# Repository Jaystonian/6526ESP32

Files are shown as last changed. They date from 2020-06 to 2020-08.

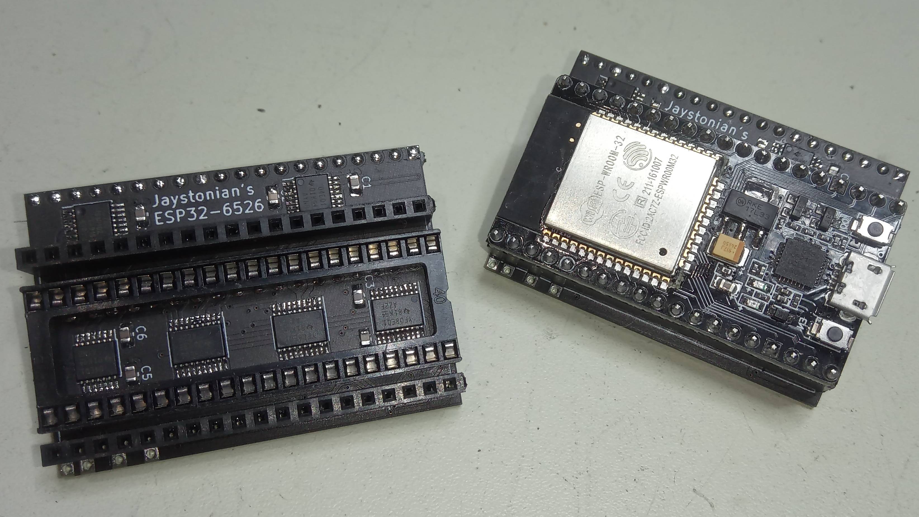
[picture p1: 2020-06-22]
pics/IMG_20200618_071035_0.jpg

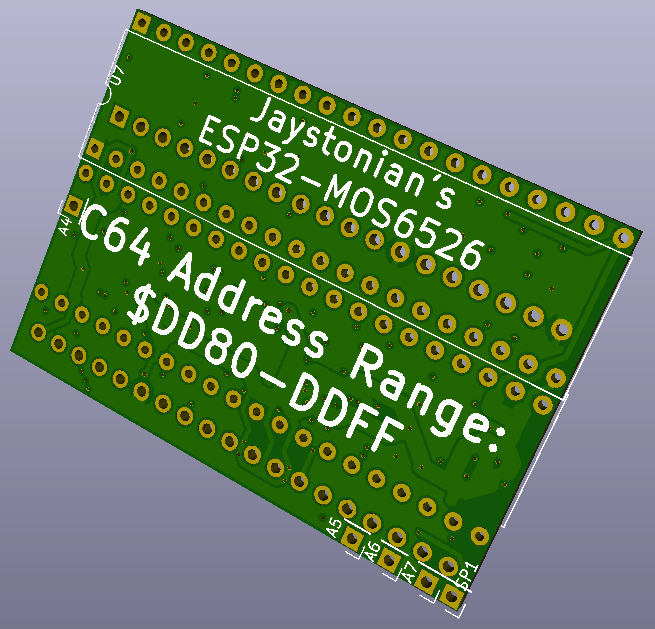
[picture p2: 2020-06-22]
pics/6526ESP32-Bottom.png

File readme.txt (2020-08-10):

6526ESP32

v0.1 - Largely disabled wifi, device boots into Ready mode instead of Modem mode
     - Added 1541diag cartridge (to use, poke 56704,5:poke 56705,0:sys56777)
     - Added Tool-64 cartridge (to use, poke 56704,5:poke 56705,1:sys56777)
     - Intended to use a new version of BASIC with new commands to use the
     device easily without pokes or sys calls, and also replace math etc.

v0.0 - straight conversion from ESP8266, added a few things but very dirty

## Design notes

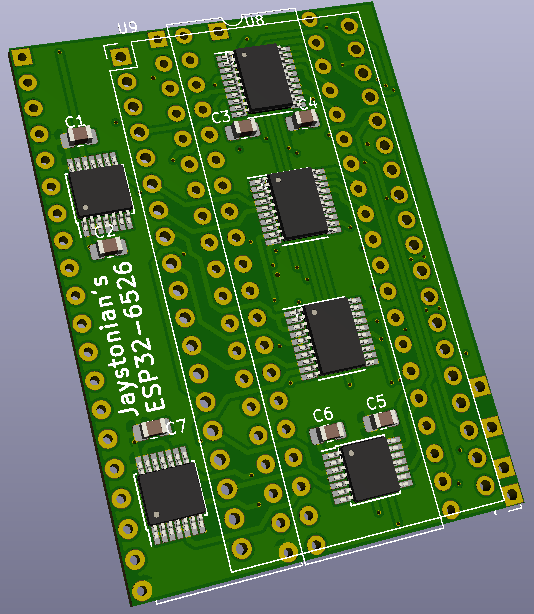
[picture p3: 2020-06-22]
pics/6526ESP32-Top.png

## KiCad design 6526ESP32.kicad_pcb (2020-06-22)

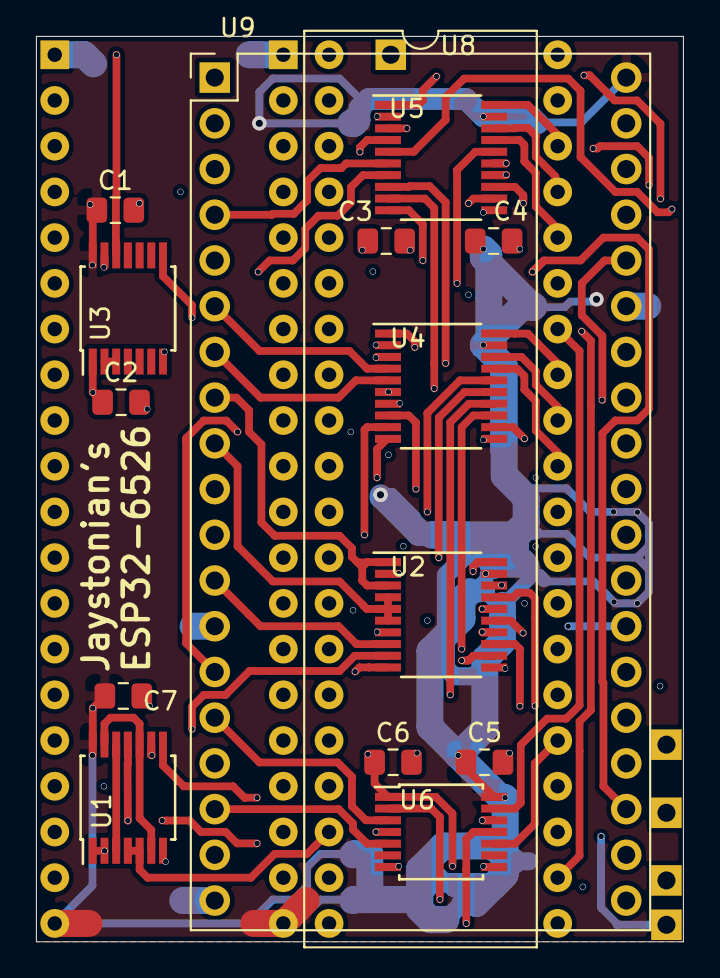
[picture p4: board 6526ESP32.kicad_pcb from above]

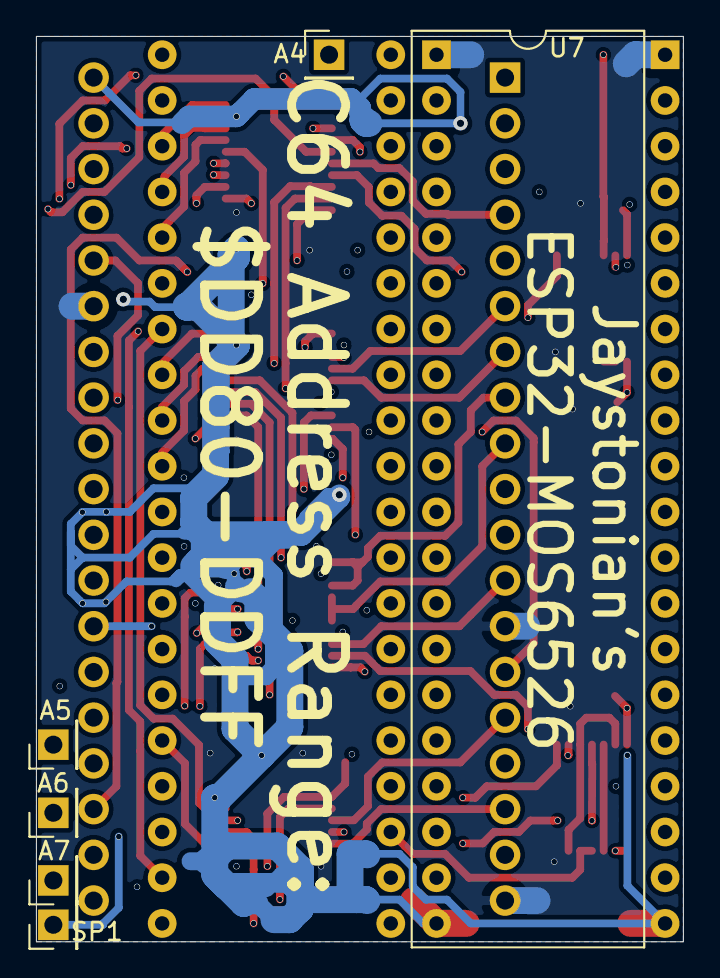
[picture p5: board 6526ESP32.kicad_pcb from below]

Board: 4 copper layers, 35.9 x 50.3 mm, 21 parts (5 on the bottom side), 78 nets.

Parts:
A4: A4; PinHeader_1x01_P2.54mm_Vertical
A5: A5; PinHeader_1x01_P2.54mm_Vertical
A6: A6; PinHeader_1x01_P2.54mm_Vertical
A7: A7; PinHeader_1x01_P2.54mm_Vertical
C1, C2, C3, C4, C5, C6, C7: 100n; C_0805_2012Metric_Pad1.15x1.40mm_HandSolder
SP1: SP1; PinHeader_1x01_P2.54mm_Vertical
U1: 74ABT00PW,112; TSSOP-14_4.4x5mm_P0.65mm
U2, U4, U5: TXS0108EQPWRQ1; TSSOP-20_4.4x6.5mm_P0.65mm
U3, U6: TXS0104EPW; TSSOP-14_4.4x5mm_P0.65mm
U7: MOS6526_SOCKET; DIP-40_W15.24mm
U8: MOS6526_CHIP; DIP-40_W15.24mm
U9: ESP32-DEVKIT-C; ESP32-DEV1

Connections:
+3V3: C2.1, C3.1, C6.1, U2.2, U3.1, U4.2, U5.2, U6.1, U6.8, U9.20
+5V: C1.1, C4.1, C5.1, C7.1, U1.14, U2.19, U3.14, U4.19, U5.19, U6.14, U7.20, U8.20, U9.38
/A0: U5.20, U7.38, U8.38
/A0_3V: U5.1, U9.24
/A1: U5.18, U7.37, U8.37
/A1_3V: U5.3, U9.25
/A2: U5.17, U7.36, U8.36
/A2_3V: U5.4, U9.22
/A3: U5.16, U7.35, U8.35
/A3_3V: U5.5, U9.23
/A4: A4.1, U5.15
/A4_3V: U5.6, U9.4
/A5: A5.1, U5.14
/A5_3V: U5.7, U9.10
/A6: A6.1, U5.13
/A6_3V: U5.8, U9.31
/A7: A7.1, U1.1, U1.2, U1.9
/CHIP~RESET: U6.13, U7.34, U8.34
/CHIP~RESET~3V: U6.2, U9.21
/CLK: U6.10, U7.25, U8.25
/CLK_3V: U6.5, U9.17
/CNT2: U3.12, U7.40, U8.40
/D0: U4.20, U7.33, U8.33
/D0_3V: U4.1, U9.27
/D1: U4.18, U7.32, U8.32
/D1_3V: U4.3, U9.14
/D2: U4.17, U7.31, U8.31
/D2_3V: U4.4, U9.6
/D3: U4.16, U7.30, U8.30
/D3_3V: U4.5, U9.7
/D4: U4.15, U7.29, U8.29
/D4_3V: U4.6, U9.30
/D5: U4.12, U7.28, U8.28
/D5_3V: U4.9, U9.28
/D6: U4.13, U7.27, U8.27
/D6_3V: U4.8, U9.29
/D7: U4.14, U7.26, U8.26
/D7_3V: U4.7, U9.34
/ENABLEMODEM_3V: U2.10, U3.8, U9.5
/GATE_ENABLE_3V: U4.10, U5.10, U9.32
/MODEM_CTS_3V: U2.8, U9.12
/MODEM_DCD_3V: U2.9, U9.18
/MODEM_RTS_3V: U2.7, U9.11
/MODEM_RXD_3V: U2.1, U2.3, U9.8
/MODEM_TXD_3V: U2.4, U2.5, U2.6, U9.9
/PA0: U7.2, U8.2
/PA1: U7.3, U8.3
/PA2: U2.20, U7.4, U8.4
/PA3: U7.5, U8.5
/PA4: U7.6, U8.6
/PA5: U7.7, U8.7
/PA6: U7.8, U8.8
/PA7: U7.9, U8.9
/PB0: U2.16, U7.10, U8.10
/PB1: U2.14, U7.11, U8.11
/PB2: U7.12, U8.12
/PB3: U7.13, U8.13
/PB4: U2.12, U7.14, U8.14
/PB5: U7.15, U8.15
/PB6: U2.13, U7.16, U8.16
/PB7: U3.13, U7.17, U8.17
/R~W: U5.12, U7.22, U8.22
/R~W~_3V: U5.9, U9.26
/SP1: SP1.1, U2.18
/SP2: U2.15, U7.39, U8.39
/TOD: U7.19, U8.19
/~CE: U1.4, U1.5, U7.23
/~CE6526: U1.11, U8.23
/~CHIPSELECT: U1.8, U6.12
/~CHIPSELECT3V: U6.3, U9.15
/~FLAG2: U2.17, U7.24, U8.24
/~NMI: U6.11, U7.21, U8.21
/~NMI_3V: U6.4, U9.16
/~PC: U7.18, U8.18
GND: C1.2, C2.2, C3.2, C4.2, C5.2, C6.2, C7.2, U1.7, U2.11, U3.7, U4.11, U5.11, U6.7, U7.1, U8.1, U9.13, U9.19, U9.33
unnamed: U1.6, U1.10, U1.13
unnamed: U1.3, U1.12
unnamed: U3.2, U3.3

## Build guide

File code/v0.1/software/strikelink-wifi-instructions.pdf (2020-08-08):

## Strikelink WiFi Instructions

I hope you enjoy your new Strikelink WiFi! The esp8266 module on the board has already been flashed with the latest firmware and pre-configured for 9600 baud use.

To get the proper use out of your unit, do the following to set up:

1. With your C64 powered OFF, Plug the Strikelink WiFi into the C64 User Port, Strikelink WiFi Logo side UP.
2. Turn on computer, and load CCGMS 2017 v4
3. Press F7 to enter the program settings menu, select UP9600 / EZ232 under modem type, and change the baud rate to 9600 baud
4. Save Phonebook and Config
5. Press Return to enter Terminal Mode
6. Press Return. Your Strikelink should say hello to you!
7. Press F8 to enter Anscii Mode (Anscii is a combination of Ascii and Ansi. CCGMS will interpret Ansi colors in Ascii mode). Anscii mode helps the modem properly interpret your WiFi router SSID and Password.
8. Type at$ssid=yourssidgoeshere (Then press Return)
9. Type at$pass=yourpasswordgoeshere (Then press Return)
10.Type atc1 to Connect (atc1 connects to your WiFi, atc0 disconnects)
11.Type at&w to write your settings to the Strikelink WiFi. These will be permanently saved, so in the future, you can load CCGMS 2017 v4, press return, and you should automatically be ready to call BBSes. If your Strikelink ever fails to connect to your router / WiFi access point, just type atc1 to try connecting again.
12.Press F8 to return to Graphics mode, and use the Autodialer in CCGMS 2017 v4 to start calling C64 BBS Systems. You can save your User ID and Password for BBSes in CCGMS 2017 v4 and send them to the BBS you call by pressing F6 and F8, respectively. It makes logging in much easier!

Notes:

– You should be able to stay in 9600 baud mode for most boards you call, even boards that run at lower baud rates. If you ever need to change your baud rate on the Strikelink, just type at$sb=newbaudrate in terminal mode (ex. at$sb=2400), then switch to the F7 menu in CCGMS 2017 v4 and select the corresponding baud rate (ex.2400). Return to terminal mode, and you will now be operating at your new baud rate.
– If you switch to use the User Port 300-2400 modem type in CCGMS 2017 v4 (instead of the UP9600 / EZ232 modem), you'll need to turn off hardware flow control. at&k0 will turn off hardware flow control. at&k1 will turn it back on. You must have hardware flow control on when using the UP9600 / EZ232 modem or bad things will happen :). As the UP9600 / EZ232 modem setting should be fine for calling all BBS Systems, you should really never need to do this.
– The terminal command 'at?' should give you a list of available modem at commands. If this flies by too fast, switch to 2400 baud to see the full menu.
– If your WiFi ever stops working, use the reset button on the WiFi unit or power off your C64 and restart your computer.
– DO NOT USE external 5v usb power at the same time you have your Strikelink WiFi plugged in. This could damage your Strikelink or C64. If you wish to use external usb power instead of the C64 power, cut the trace going to pin 2 on the c64 user port. (top of the board, right side). The Strikelink could draw too much current on C64s not utilizing a newer heavy duty power supply, causing issues. In that case, cutting the trace and using external power is recommended.

How to use external USB power instead of C64 Power.

## This is the top side of the board, with the Strikelink WiFi logo on the

left side.

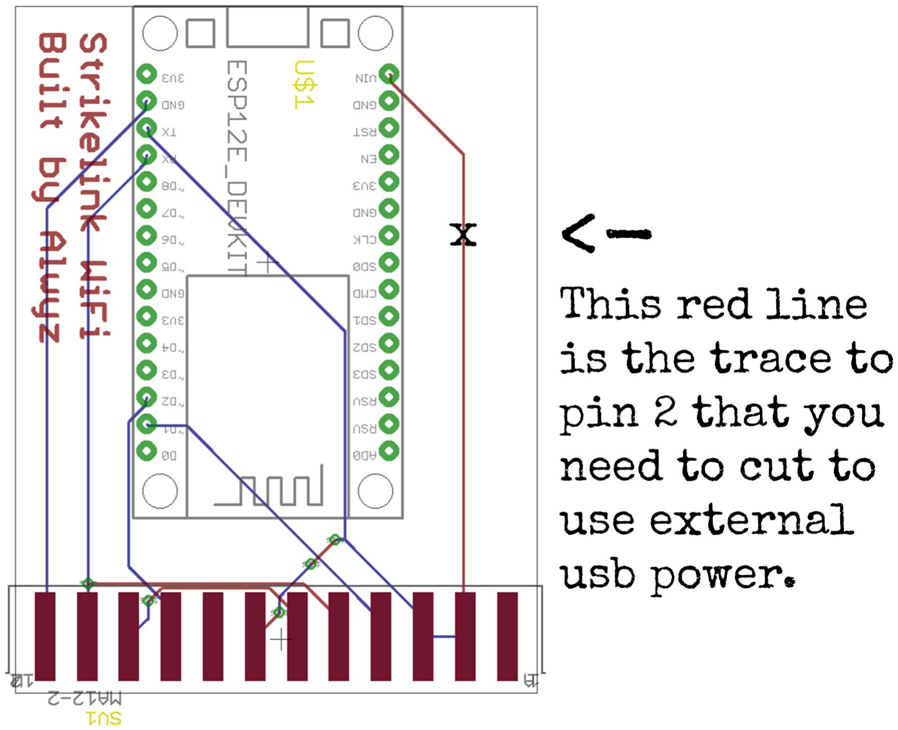
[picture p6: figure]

You can use a small screwdriver edge or other small tool to cut the line on the board.

### To test if your cut was effective, plug your Strikelink WiFi into the C64 without the usb

power plugged in, and make sure the blue light on the Strikelink WiFi does NOT turn on.

At this point it is safe to plug in external usb power.

### When using external usb power, it is recommended to power on the Strikelink WiFi

before turning on your C64.

In case of accidental firmware factory reset (at&f), set ccgms to 300 baud to connect, then issue the following commands, at&p0, at&k1, and at$sb=9600.

### Questions: http://1200baud.wordpress.com – alwyz@sceneworld.org

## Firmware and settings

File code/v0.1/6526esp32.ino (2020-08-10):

/*
  6526ESP32 - A virtual WiFi modem and C64/C128 coprocessor 
    for MOS6526 & NodeMCU-32S (Commodore C64 & C128)
    https://github.com/Jaystonian/6526ESP32
    
    To use, follow instructions for StrikeLink WiFi or updated PDF specific to this project.
    C64/C128 CCGMS available here: https://commodore.software/downloads/category/59-ccgms

                            --- based on ---
    
   https://github.com/svenpetersen1965/C64-WiFi-Modem-User-Port    

                            --- based on ---
   https://1200baud.wordpress.com/2017/03/04/build-your-own-9600-baud-c64-wifi-modem-for-20/

   WiFi SIXFOUR - A virtual WiFi modem based on the ESP 8266 chipset
   Copyright (C) 2016 Paul Rickards <rickards@gmail.com>

   based on
   ESP8266 based virtual modem
   Copyright (C) 2016 Jussi Salin <salinjus@gmail.com>

   https://github.com/jsalin/esp8266_modem

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
   You should have received a copy of the GNU General Public License
   along with this program.  If not, see <http://www.gnu.org/licenses/>.
*/

#include <WiFi.h>
#include "ESP32WebServer.h"
#include <EEPROM.h>
#include <ESPmDNS.h>
#include <time.h>
#include "carts/1541diag.h"
#include "carts/tool64.h"

//#define DEBUG

// These translation tables are not used yet.
static unsigned char petToAscTable[256] = {
0x00,0x01,0x02,0x03,0x04,0x05,0x06,0x07,0x14,0x09,0x0d,0x11,0x93,0x0a,0x0e,0x0f,
0x10,0x0b,0x12,0x13,0x08,0x15,0x16,0x17,0x18,0x19,0x1a,0x1b,0x1c,0x1d,0x1e,0x1f,
0x20,0x21,0x22,0x23,0x24,0x25,0x26,0x27,0x28,0x29,0x2a,0x2b,0x2c,0x2d,0x2e,0x2f,
0x30,0x31,0x32,0x33,0x34,0x35,0x36,0x37,0x38,0x39,0x3a,0x3b,0x3c,0x3d,0x3e,0x3f,
0x40,0x61,0x62,0x63,0x64,0x65,0x66,0x67,0x68,0x69,0x6a,0x6b,0x6c,0x6d,0x6e,0x6f,
0x70,0x71,0x72,0x73,0x74,0x75,0x76,0x77,0x78,0x79,0x7a,0x5b,0x5c,0x5d,0x5e,0x5f,
0xc0,0xc1,0xc2,0xc3,0xc4,0xc5,0xc6,0xc7,0xc8,0xc9,0xca,0xcb,0xcc,0xcd,0xce,0xcf,
0xd0,0xd1,0xd2,0xd3,0xd4,0xd5,0xd6,0xd7,0xd8,0xd9,0xda,0xdb,0xdc,0xdd,0xde,0xdf,
0x80,0x81,0x82,0x83,0x84,0x85,0x86,0x87,0x88,0x89,0x8a,0x8b,0x8c,0x8d,0x8e,0x8f,
0x90,0x91,0x92,0x0c,0x94,0x95,0x96,0x97,0x98,0x99,0x9a,0x9b,0x9c,0x9d,0x9e,0x9f,
0xa0,0xa1,0xa2,0xa3,0xa4,0xa5,0xa6,0xa7,0xa8,0xa9,0xaa,0xab,0xac,0xad,0xae,0xaf,
0xb0,0xb1,0xb2,0xb3,0xb4,0xb5,0xb6,0xb7,0xb8,0xb9,0xba,0xbb,0xbc,0xbd,0xbe,0xbf,
0x60,0x41,0x42,0x43,0x44,0x45,0x46,0x47,0x48,0x49,0x4a,0x4b,0x4c,0x4d,0x4e,0x4f,
0x50,0x51,0x52,0x53,0x54,0x55,0x56,0x57,0x58,0x59,0x5a,0x7b,0x7c,0x7d,0x7e,0x7f,
0xa0,0xa1,0xa2,0xa3,0xa4,0xa5,0xa6,0xa7,0xa8,0xa9,0xaa,0xab,0xac,0xad,0xae,0xaf,
0xb0,0xb1,0xb2,0xb3,0xb4,0xb5,0xb6,0xb7,0xb8,0xb9,0xba,0xbb,0xbc,0xbd,0xbe,0xbf
};

static unsigned char ascToPetTable[256] = {
0x00,0x01,0x02,0x03,0x04,0x05,0x06,0x07,0x14,0x09,0x0d,0x11,0x93,0x0a,0x0e,0x0f,
0x10,0x0b,0x12,0x13,0x08,0x15,0x16,0x17,0x18,0x19,0x1a,0x1b,0x1c,0x1d,0x1e,0x1f,
0x20,0x21,0x22,0x23,0x24,0x25,0x26,0x27,0x28,0x29,0x2a,0x2b,0x2c,0x2d,0x2e,0x2f,
0x30,0x31,0x32,0x33,0x34,0x35,0x36,0x37,0x38,0x39,0x3a,0x3b,0x3c,0x3d,0x3e,0x3f,
0x40,0xc1,0xc2,0xc3,0xc4,0xc5,0xc6,0xc7,0xc8,0xc9,0xca,0xcb,0xcc,0xcd,0xce,0xcf,
0xd0,0xd1,0xd2,0xd3,0xd4,0xd5,0xd6,0xd7,0xd8,0xd9,0xda,0x5b,0x5c,0x5d,0x5e,0x5f,
0xc0,0x41,0x42,0x43,0x44,0x45,0x46,0x47,0x48,0x49,0x4a,0x4b,0x4c,0x4d,0x4e,0x4f,
0x50,0x51,0x52,0x53,0x54,0x55,0x56,0x57,0x58,0x59,0x5a,0xdb,0xdc,0xdd,0xde,0xdf,
0x80,0x81,0x82,0x83,0x84,0x85,0x86,0x87,0x88,0x89,0x8a,0x8b,0x8c,0x8d,0x8e,0x8f,
0x90,0x91,0x92,0x0c,0x94,0x95,0x96,0x97,0x98,0x99,0x9a,0x9b,0x9c,0x9d,0x9e,0x9f,
0xa0,0xa1,0xa2,0xa3,0xa4,0xa5,0xa6,0xa7,0xa8,0xa9,0xaa,0xab,0xac,0xad,0xae,0xaf,
0xb0,0xb1,0xb2,0xb3,0xb4,0xb5,0xb6,0xb7,0xb8,0xb9,0xba,0xbb,0xbc,0xbd,0xbe,0xbf,
0x60,0x61,0x62,0x63,0x64,0x65,0x66,0x67,0x68,0x69,0x6a,0x6b,0x6c,0x6d,0x6e,0x6f,
0x70,0x71,0x72,0x73,0x74,0x75,0x76,0x77,0x78,0x79,0x7a,0x7b,0x7c,0x7d,0x7e,0x7f,
0xe0,0xe1,0xe2,0xe3,0xe4,0xe5,0xe6,0xe7,0xe8,0xe9,0xea,0xeb,0xec,0xed,0xee,0xef,
0xf0,0xf1,0xf2,0xf3,0xf4,0xf5,0xf6,0xf7,0xf8,0xf9,0xfa,0xfb,0xfc,0xfd,0xfe,0xff
};

#define VERSIONA 0
#define VERSIONB 1
#define VERSION_ADDRESS 0    // EEPROM address
#define VERSION_LEN     2    // Length in bytes
#define SSID_ADDRESS    2
#define SSID_LEN        32
#define PASS_ADDRESS    34
#define PASS_LEN        63
#define IP_TYPE_ADDRESS 97   // for future use
#define STATIC_IP_ADDRESS 98 // length 4, for future use
#define STATIC_GW       102  // length 4, for future use
#define STATIC_DNS      106  // length 4, for future use
#define STATIC_MASK     110  // length 4, for future use
#define BAUD_ADDRESS    111
#define ECHO_ADDRESS    112
#define SERVER_PORT_ADDRESS 113 // 2 bytes
#define AUTO_ANSWER_ADDRESS 115 // 1 byte
#define TELNET_ADDRESS  116     // 1 byte
#define VERBOSE_ADDRESS 117
#define PET_TRANSLATE_ADDRESS 118
#define FLOW_CONTROL_ADDRESS 119
#define PIN_POLARITY_ADDRESS 120
#define DIAL0_ADDRESS   200
#define DIAL1_ADDRESS   250
#define DIAL2_ADDRESS   300
#define DIAL3_ADDRESS   350
#define DIAL4_ADDRESS   400
#define DIAL5_ADDRESS   450
#define DIAL6_ADDRESS   500
#define DIAL7_ADDRESS   550
#define DIAL8_ADDRESS   600
#define DIAL9_ADDRESS   650
#define BUSY_MSG_ADDRESS 700
#define BUSY_MSG_LEN    80
#define LAST_ADDRESS    780

///////////////////////////////////////////////////////////////////////////////////


#define PortD00 25
#define PortD01 21
#define PortD02 0 
#define PortD03 4
#define PortD04 27
#define PortD05 25
#define PortD06 26
#define PortD07 13

#define PortA0 34
#define PortA1 35
#define PortA2 36
#define PortA3 39
#define PortA4 15
#define PortA5 5
#define PortA6 14

#define PortCLK 22
#define PortRW 32
#define PortCS 3 //CHIPSELECT
#define PortNMI 1
#define PortMODEMENABLE 2 //Blue LED
#define PortGATEENABLE 12 //set low to disable
#define PortMODEM_RTS 18
#define PortMODEM_CTS 19
#define PortMODEM_DCD 23
#define PortMODEM_TXD 17
#define PortMODEM_RXD 16



// Global variables
String build = "20200808162000";
String cmd = "";           // Gather a new AT command to this string from serial
bool cmdMode = true;       // Are we in AT command mode or connected mode
bool callConnected = false;// Are we currently in a call
bool telnet = false;       // Is telnet control code handling enabled
bool verboseResults = false;
//#define DEBUG 1          // Print additional debug information to serial channel
//#undef DEBUG
#define LISTEN_PORT 6400   // Listen to this if not connected. Set to zero to disable.
int tcpServerPort = LISTEN_PORT;
#define RING_INTERVAL 3000 // How often to print RING when having a new incoming connection (ms)
unsigned long lastRingMs = 0; // Time of last "RING" message (millis())
//long myBps;                // What is the current BPS setting
#define MAX_CMD_LENGTH 256 // Maximum length for AT command
char plusCount = 0;        // Go to AT mode at "+++" sequence, that has to be counted
unsigned long plusTime = 0;// When did we last receive a "+++" sequence
#define LED_TIME 15         // How many ms to keep LED on at activity
unsigned long ledTime = 0;
#define TX_BUF_SIZE 256    // Buffer where to read from serial before writing to TCP
// (that direction is very blocking by the ESP TCP stack,
// so we can't do one byte a time.)
uint8_t txBuf[TX_BUF_SIZE];
const int speedDialAddresses[] = { DIAL0_ADDRESS, DIAL1_ADDRESS, DIAL2_ADDRESS, DIAL3_ADDRESS, DIAL4_ADDRESS, DIAL5_ADDRESS, DIAL6_ADDRESS, DIAL7_ADDRESS, DIAL8_ADDRESS, DIAL9_ADDRESS };
String speedDials[10];
const int bauds[] = { 300, 1200, 2400, 4800, 9600, 19200, 38400, 57600, 115200 };
byte serialspeed;
bool echo = true;
bool autoAnswer = false;
String ssid, password, busyMsg;
byte ringCount = 0;
String resultCodes[] = { "OK", "CONNECT", "RING", "NO CARRIER", "ERROR", "", "NO DIALTONE", "BUSY", "NO ANSWER" };
enum resultCodes_t { RR_OK, R_CONNECT, R_RING, R_NOCARRIER, R_ERROR, R_NONE, R_NODIALTONE, R_BUSY, R_NOANSWER };

unsigned long connectTime = 0;
bool petTranslate = false; // Fix PET MCTerm 1.26C Pet->ASCII encoding to actual ASCII
bool hex = false;
enum flowControl_t { F_NONE, F_HARDWARE, F_SOFTWARE };
byte flowControl = F_NONE;      // Use flow control
bool txPaused = false;          // Has flow control asked us to pause?
enum pinPolarity_t { P_INVERTED, P_NORMAL }; // Is LOW (0) or HIGH (1) active?
byte pinPolarity = P_INVERTED;

// Telnet codes
#define DO 0xfd
#define WONT 0xfc
#define WILL 0xfb
#define DONT 0xfe

#define SYSRESET 64738

WiFiClient tcpClient;
WiFiServer tcpServer(tcpServerPort);
ESP32WebServer webServer(80);
MDNSResponder mdns;
HardwareSerial SerialSM(1);




//////////////////////////////////////////////////////////////////////////////////////////////////////////////////////////////////////////////////////////////////////
bool cbCLK = false, cbCLK_OLD = false, cbCLK_NEG = false, cbCLK_POS = false; uint cuCLK_time=0, cuCLK=0;
bool cbRW = false, cbRW_OLD = false, cbRW_NEG = false, cbRW_POS = false; uint cuRW_time=0, cuRW=0;
bool cbCS = false, cbCS_OLD = false, cbCS_NEG = false, cbCS_POS = false; uint cuCS_time=0, cuCS=0;

uint cuWaitCS = 20;
uint cuWaitRW = 20;
uint cuWaitCLK = 20;

#define DATAPAGESIZE 128
byte cnAddress = 0, cnAddress_OLD = 0;
bool cbEnabledModem = false;
bool cbEnabledAddressing = false;
byte cnDataPage[DATAPAGESIZE]; //byte storage for DD80-DDFF
uint cnByteCounter = 0;
uint cnByteDest = 0;
byte cnMode = 0, cnMode_old = 0;
byte cnCommand = 0, cnCommand_old = 0;
const int cnWaitTime = 1000;
uint lastCycle = 0;


void checkStateTransitions(){ // neg/pos get set on edges
  //not all of this is going to be needed but will help with debug
  uint thisCycle = ESP.getCycleCount();  
  
  cbCLK=digitalRead(PortCLK);
  cbRW=digitalRead(PortRW);
  cbCS=digitalRead(PortCS);
  
  if(cbCLK!=cbCLK_OLD){cbCLK_OLD=cbCLK;cbCLK_NEG=!cbCLK;cbCLK_POS=cbCLK;cuCLK_time=thisCycle;}
  if(cbRW!=cbRW_OLD){cbRW_OLD=cbRW;cbRW_NEG=!cbRW;cbRW_POS=cbRW;cuRW_time=thisCycle;}
  if(cbCS!=cbCS_OLD){cbCS_OLD=cbCS;cbCS_NEG=!cbCS;cbCS_POS=cbCS;cuCS_time=thisCycle;}

  cuCLK = thisCycle - cuCLK_time;
  cuRW = thisCycle - cuRW_time;
  cuCS = thisCycle - cuCS_time;
  
}

void enableAddressing(bool bEnable){
  //if(cbEnabledAddressing == bEnable) return;
  cbEnabledAddressing = bEnable;
  if(bEnable){
    enableModem(false);
    digitalWrite(PortGATEENABLE,HIGH);
  }else{
    digitalWrite(PortGATEENABLE,LOW);
  }
}
void enableModem(bool bEnable) {
  //if(cbEnabledModem == bEnable) return;
  cbEnabledModem = bEnable;
  if(bEnable){
    enableAddressing(false);
    digitalWrite(PortMODEMENABLE, HIGH);
    digitalWrite(PortMODEM_RTS, HIGH); // ready to receive data
  }else{
    digitalWrite(PortMODEMENABLE, LOW);
  }

}

void setDataRead()
{
  if(cbRW){ //read means output data
    pinMode(PortD00,OUTPUT);
    pinMode(PortD01,OUTPUT);
    pinMode(PortD02,OUTPUT);
    pinMode(PortD03,OUTPUT);
    pinMode(PortD04,OUTPUT);
    pinMode(PortD05,OUTPUT);
    pinMode(PortD06,OUTPUT);
    pinMode(PortD07,OUTPUT);
  }else{ //write is active-low
    pinMode(PortD00,INPUT);
    pinMode(PortD01,INPUT);
    pinMode(PortD02,INPUT);
    pinMode(PortD03,INPUT);
    pinMode(PortD04,INPUT);
    pinMode(PortD05,INPUT);
    pinMode(PortD06,INPUT);
    pinMode(PortD07,INPUT);
  }
  
}

void putByteData(byte nData){
  //RW must be HIGH before this call
  digitalWrite(PortD07,nData & 128);
  digitalWrite(PortD06,nData & 64);
  digitalWrite(PortD05,nData & 32);
  digitalWrite(PortD04,nData & 16);
  digitalWrite(PortD03,nData & 8);
  digitalWrite(PortD02,nData & 4);
  digitalWrite(PortD01,nData & 2);
  digitalWrite(PortD00,nData & 1);
}
byte getByteData()
{
  //assume RW is LOW before this call
  byte bIn = (digitalRead(PortD07)?1:0);
  bIn = bIn << 1 + (digitalRead(PortD06)?1:0);
  bIn = bIn << 1 + (digitalRead(PortD05)?1:0);
  bIn = bIn << 1 + (digitalRead(PortD04)?1:0);
  bIn = bIn << 1 + (digitalRead(PortD03)?1:0);
  bIn = bIn << 1 + (digitalRead(PortD02)?1:0);
  bIn = bIn << 1 + (digitalRead(PortD01)?1:0);
  bIn = bIn << 1 + (digitalRead(PortD00)?1:0);
}
byte getByteAddress()
{
  byte bIn = 2;
  bIn += (digitalRead(PortA6)?1:0);
  bIn = bIn << 1 + (digitalRead(PortA5)?1:0);
  bIn = bIn << 1 + (digitalRead(PortA4)?1:0);
  bIn = bIn << 1 + (digitalRead(PortA3)?1:0);
  bIn = bIn << 1 + (digitalRead(PortA2)?1:0);
  bIn = bIn << 1 + (digitalRead(PortA1)?1:0);
  bIn = bIn << 1 + (digitalRead(PortA0)?1:0);
}





////////////////////////////////////////////////////////////////////////////////////////////////
String connectTimeString() {
  unsigned long now = millis();
  int secs = (now - connectTime) / 1000;
  int mins = secs / 60;
  int hours = mins / 60;
  String out = "";
  if (hours < 10) out.concat("0");
  out.concat(String(hours));
  out.concat(":");
  if (mins % 60 < 10) out.concat("0");
  out.concat(String(mins % 60));
  out.concat(":");
  if (secs % 60 < 10) out.concat("0");
  out.concat(String(secs % 60));
  return out;
}

void writeSettings() {
  setEEPROM(ssid, SSID_ADDRESS, SSID_LEN);
  setEEPROM(password, PASS_ADDRESS, PASS_LEN);
  setEEPROM(busyMsg, BUSY_MSG_ADDRESS, BUSY_MSG_LEN);

  EEPROM.write(BAUD_ADDRESS, serialspeed);
  EEPROM.write(ECHO_ADDRESS, byte(echo));
  EEPROM.write(AUTO_ANSWER_ADDRESS, byte(autoAnswer));
  EEPROM.write(SERVER_PORT_ADDRESS, highByte(tcpServerPort));
  EEPROM.write(SERVER_PORT_ADDRESS + 1, lowByte(tcpServerPort));
  EEPROM.write(TELNET_ADDRESS, byte(telnet));
  EEPROM.write(VERBOSE_ADDRESS, byte(verboseResults));
  EEPROM.write(PET_TRANSLATE_ADDRESS, byte(petTranslate));
  EEPROM.write(FLOW_CONTROL_ADDRESS, byte(flowControl));
  EEPROM.write(PIN_POLARITY_ADDRESS, byte(pinPolarity));

  for (int i = 0; i < 10; i++) {
    setEEPROM(speedDials[i], speedDialAddresses[i], 50);
  }
  EEPROM.commit();
}

void readSettings() {
  echo = EEPROM.read(ECHO_ADDRESS);
  autoAnswer = EEPROM.read(AUTO_ANSWER_ADDRESS);
  // serialspeed = EEPROM.read(BAUD_ADDRESS);

  ssid = getEEPROM(SSID_ADDRESS, SSID_LEN);
  password = getEEPROM(PASS_ADDRESS, PASS_LEN);
  busyMsg = getEEPROM(BUSY_MSG_ADDRESS, BUSY_MSG_LEN);
  tcpServerPort = word(EEPROM.read(SERVER_PORT_ADDRESS), EEPROM.read(SERVER_PORT_ADDRESS + 1));
  telnet = EEPROM.read(TELNET_ADDRESS);
  verboseResults = EEPROM.read(VERBOSE_ADDRESS);
  petTranslate = EEPROM.read(PET_TRANSLATE_ADDRESS);
  flowControl = EEPROM.read(FLOW_CONTROL_ADDRESS);
  pinPolarity = EEPROM.read(PIN_POLARITY_ADDRESS);

  for (int i = 0; i < 10; i++) {
    speedDials[i] = getEEPROM(speedDialAddresses[i], 50);
  }
}

void defaultEEPROM() {
  EEPROM.write(VERSION_ADDRESS, VERSIONA);
  EEPROM.write(VERSION_ADDRESS + 1, VERSIONB);

  setEEPROM("", SSID_ADDRESS, SSID_LEN);
  setEEPROM("", PASS_ADDRESS, PASS_LEN);
  setEEPROM("d", IP_TYPE_ADDRESS, 1);
  EEPROM.write(SERVER_PORT_ADDRESS, highByte(LISTEN_PORT));
  EEPROM.write(SERVER_PORT_ADDRESS + 1, lowByte(LISTEN_PORT));

  EEPROM.write(BAUD_ADDRESS, 0x00);
  EEPROM.write(ECHO_ADDRESS, 0x01);
  EEPROM.write(AUTO_ANSWER_ADDRESS, 0x01);
  EEPROM.write(TELNET_ADDRESS, 0x00);
  EEPROM.write(VERBOSE_ADDRESS, 0x01);
  EEPROM.write(PET_TRANSLATE_ADDRESS, 0x00);
  EEPROM.write(FLOW_CONTROL_ADDRESS, 0x00);
  EEPROM.write(PIN_POLARITY_ADDRESS, 0x01);

  setEEPROM("bbs.fozztexx.com:23", speedDialAddresses[0], 50);
  setEEPROM("cottonwoodbbs.dyndns.org:6502", speedDialAddresses[1], 50);
  setEEPROM("borderlinebbs.dyndns.org:6400", speedDialAddresses[2], 50);
  setEEPROM("particlesbbs.dyndns.org:6400", speedDialAddresses[3], 50);
  setEEPROM("reflections.servebbs.com:23", speedDialAddresses[4], 50);
  setEEPROM("heatwavebbs.com:9640", speedDialAddresses[5], 50);

  for (int i = 5; i < 10; i++) {
    setEEPROM("", speedDialAddresses[i], 50);
  }

  setEEPROM("SORRY, SYSTEM IS CURRENTLY BUSY. PLEASE TRY AGAIN LATER.", BUSY_MSG_ADDRESS, BUSY_MSG_LEN);
  EEPROM.commit();
}

String getEEPROM(int startAddress, int len) {
  String myString;

  for (int i = startAddress; i < startAddress + len; i++) {
    if (EEPROM.read(i) == 0x00) {
      break;
    }
    myString += char(EEPROM.read(i));
    //SerialSM.print(char(EEPROM.read(i)));
  }
  //SerialSM.println();
  return myString;
}

void setEEPROM(String inString, int startAddress, int maxLen) {
  for (int i = startAddress; i < inString.length() + startAddress; i++) {
    EEPROM.write(i, inString[i - startAddress]);
    //SerialSM.print(i, DEC); SerialSM.print(": "); SerialSM.println(inString[i - startAddress]);
    //if (EEPROM.read(i) != inString[i - startAddress]) { SerialSM.print(" (!)"); }
    //SerialSM.println();
  }
  // null pad the remainder of the memory space
  for (int i = inString.length() + startAddress; i < maxLen + startAddress; i++) {
    EEPROM.write(i, 0x00);
    //SerialSM.print(i, DEC); SerialSM.println(": 0x00");
  }
}

void sendResult(int resultCode) {
  SerialSM.print("\r\n");
  if (verboseResults == 0) {
    SerialSM.println(resultCode);
    return;
  }
  if (resultCode == R_CONNECT) {
    SerialSM.print(String(resultCodes[R_CONNECT]) + " " + String(bauds[serialspeed]));
  } else if (resultCode == R_NOCARRIER) {
    SerialSM.print(String(resultCodes[R_NOCARRIER]) + " (" + connectTimeString() + ")");
  } else {
    SerialSM.print(String(resultCodes[resultCode]));
  }
  SerialSM.print("\r\n");
}

void sendString(String msg) {
  SerialSM.print("\r\n");
  SerialSM.print(msg);
  SerialSM.print("\r\n");
}

// Hold for 5 seconds to switch to 300 baud
// Slow flash: keep holding
// Fast flash: let go
//JWD:replace functionality for switch with configuration code
int checkButton() {
  /*
  long time = millis();
  while (digitalRead(SWITCH_PIN) == LOW && millis() - time < 5000) {
    delay(250);
    digitalWrite(LED_PIN, !digitalRead(LED_PIN));
    yield();
  }
  if (millis() - time > 5000) {
    SerialSM.flush();
    SerialSM.end();
    serialspeed = 0;
    delay(100);
    SerialSM.begin(bauds[serialspeed]);
    sendResult(RR_OK);
    while (digitalRead(SWITCH_PIN) == LOW) {
      delay(50);
      digitalWrite(LED_PIN, !digitalRead(LED_PIN));
      yield();
    }
    return 1;
  } else {
    return 0;
  }*/
  return 0;
}

void connectWiFi() {
  if (ssid == "" || password == "") {
    SerialSM.println("CONFIGURE SSID AND PASSWORD. TYPE AT? FOR HELP.");
    return;
  }
  WiFi.begin(ssid.c_str(), password.c_str());
  SerialSM.print("\nCONNECTING TO SSID "); SerialSM.print(ssid);
  uint8_t i = 0;
  while (WiFi.status() != WL_CONNECTED && i++ < 20) {
    //digitalWrite(LED_PIN, LOW);
    delay(250);
    //digitalWrite(LED_PIN, HIGH);
    delay(250);
    SerialSM.print(".");
  }
  SerialSM.println();
  if (i == 21) {
    SerialSM.print("COULD NOT CONNET TO "); SerialSM.println(ssid);
    WiFi.disconnect();
    updateLed();
  } else {
    SerialSM.print("CONNECTED TO "); SerialSM.println(WiFi.SSID());
    SerialSM.print("IP ADDRESS: "); SerialSM.println(WiFi.localIP());
    updateLed();
  }
}

void updateLed() {
  if (WiFi.status() == WL_CONNECTED) {
    //digitalWrite(LED_PIN, LOW);  // on
  } else {
    //digitalWrite(LED_PIN, HIGH); //off
  }
}

void disconnectWiFi() {
  WiFi.disconnect();
  updateLed();
}
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
void loop()
{  
  checkStateTransitions();
  
  if(cbEnabledModem) { loopWifi(); return; }
  if(!cbEnabledAddressing) return;//for now, both can be disabled... comment this line out later

  if(cbCS || (!cbCS && (cuCS_time<cuWaitCS))){
    // device not enabled/selected this cycle, or too soon after enabling to be enabled.
    pinMode(PortD00,INPUT);
    pinMode(PortD01,INPUT);
    pinMode(PortD02,INPUT);
    pinMode(PortD03,INPUT);
    pinMode(PortD04,INPUT);
    pinMode(PortD05,INPUT);
    pinMode(PortD06,INPUT);
    pinMode(PortD07,INPUT);
    return; 
  }
  //if((cuRW_time<cuWaitRW))) return; //debug

  setDataRead(); //configure data bus for read/write

  cnAddress_OLD = cnAddress;
  cnAddress = getByteAddress(); //6 bits, 0 to 127
  if(cbRW){ //read output
    putByteData(cnDataPage[cnAddress]);
    triggerByteRead();
    
  }else{ //write input
    byte nByte = getByteData();
    if(cnAddress < 3) cnDataPage[cnAddress] = nByte; // first three bytes will always be accepted for writing
    if(cnAddress==0 && cnMode != nByte){ //changing mode
      cnMode_old = cnMode;
      cnMode = nByte;
      if(cnMode_old==1 && cnMode==0) enableAddressing(true); //disables wifi
      prepareNewMode();
      return;
    }
    if(cnAddress==1 && cnCommand != nByte){ //new command
      cnCommand_old = cnCommand;
      cnCommand = nByte;
      executeCommand();
      return;
    }

    //legitimate writes
    bool bEnableWrite = false;
    switch(cnMode){
      case 3: if(cnAddress >= 7) bEnableWrite=true; break; //expression evaluator
      case 4: if(cnAddress < 72) bEnableWrite=true; break; //interactive menu
      default:;
    }
    cnDataPage[cnAddress] = nByte;
    
    //writes are commands or storage of data, or prohibited by mode.
    //writing 0 to dd80 command byte will be the only way to break out of wifi mode, by returning to Ready mode.
    //usage: set mode first (clears io space), [then set var memory], then set command byte.
  }


}

/*
bool cbCLK = false, cbCLK_OLD = false, cbCLK_NEG = false, cbCLK_POS = false; clock_t cbCLK_NEG_time=0, cbCLK_POS_time=0;
bool cbRW = false, cbRW_OLD = false, cbRW_NEG = false, cbRW_POS = false; clock_t cbRW_NEG_time=0, cbRW_POS_time=0;
bool cbCS = false, cbCS_OLD = false, cbCS_NEG = false, cbCS_POS = false; clock_t cbCS_NEG_time=0, cbCS_POS_time=0;

byte cnAddress = 0, cnAddress_OLD = 0;
bool cbEnabledModem = false;
bool cbEnabledAddressing = false;
byte cnDataPage[128];
*/

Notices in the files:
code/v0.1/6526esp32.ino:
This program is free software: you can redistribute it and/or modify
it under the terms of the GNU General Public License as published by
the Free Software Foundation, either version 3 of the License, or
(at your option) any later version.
